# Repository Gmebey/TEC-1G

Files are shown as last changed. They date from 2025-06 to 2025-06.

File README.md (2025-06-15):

# TEC-1G
Collection of Work and Addons for the TEC-1G Z80 Computer

Further information about the TEC-1G
1) Facebook Group:<br>
   -- TEC-1 Z80 Computer Group<br>
   -- https://www.facebook.com/groups/tec1z80/<br>
   
3) Article from HACKADAY.IO:<br>
   -- TEC-1G: 40 year Anniversary Z80 SBC<br>
   -- https://hackaday.io/project/193968-tec-1g-40-year-anniversary-z80-sbc<br>
   
5) Where to purchase:<br>
   -- TEC-1G Z80 Single Board Computer Kit<br>>
   -- https://www.tindie.com/products/tec1/tec-1g-z80-single-board-computer-kit/<br>

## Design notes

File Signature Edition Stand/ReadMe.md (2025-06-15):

File List:<br>
1) Assembly Instructions:    TEC-1G v1.21_Stand.docx<br>
2) 3D Model (Sketchup v8):   TEC-1G_v1.4_Rev1.skp
3) STL Files:                in STLs (folder)

The 7 Segment Display Bazel is from<br>
https://github.com/turbo-gecko/TEC/tree/main/3D%20Printing/7%20Seg%20Bezel

View Top

View Bottom

View Rear

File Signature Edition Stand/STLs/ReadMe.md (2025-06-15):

STL files:
- Rail_Right.stl
- Rail_Center.stl
- Rail_Left.stl
- Leg_Right.stl
- Leg_Center.stl
- Leg_Left.stl
- YP-05_Carrier.stl
- UPS_Frame.stl

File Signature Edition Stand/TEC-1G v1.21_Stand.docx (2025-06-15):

# Overview

This is a revised version of the stand posted by Sean Parkinson for another version of TEC-1G, which didn’t have a compatible hole pattern to the TEC-1G Signature Edition version 1.21 (TEC-1G v1.21SE).

Mark Yelich provided a DXF file for the TEC-1G v1.4SE, which has a compatible hole pattern. The DXF hole pattern file (TEC-1G_Edge-Cuts_v1.4SE.dxf) is available on GitHub.

GitHub - MarkJelic/TEC-1G: The new incarnation of the 40 year old Z80 trainer computer - Now with Fulisik LEDs! (https://github.com/MarkJelic/TEC-1G)

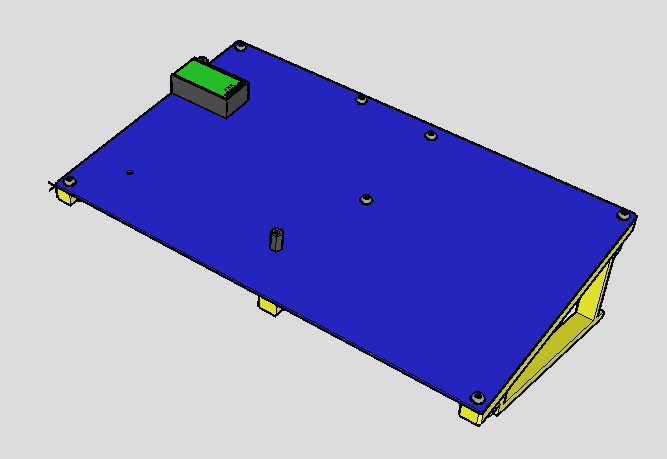
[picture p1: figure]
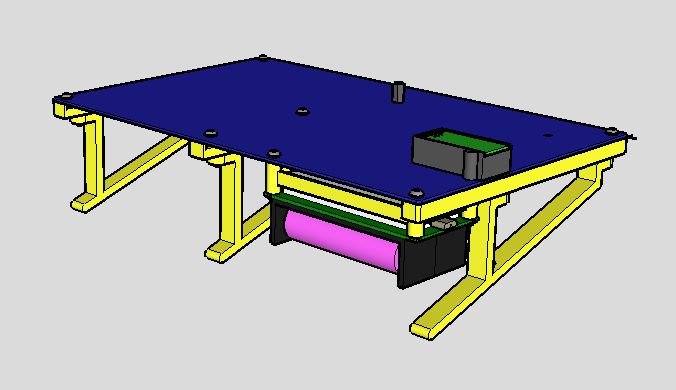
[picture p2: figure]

# Hardware

All mounting holes are intended for M3 button head screws or socket head cap screws. The holes that are provided in the 3D model will need to be drilled out to 2.5mm (#47 bit) and then tapped to M3.

Any metal screw that installed into the TEC-1G has a M3x0.5 Nylon Flat Washer to protect the nearby traces.

List of required hardware:

- 8, M3x0.5mm Nylon Flat Washer
- 9, M3x8mm Button Head Screw
- 6, M3x10mm Button Head Screw
- 1, M3x14mm Button Head Screw
- 1, M3x6mm x 10mm Nylon Hex Standoff (for LCD display)

# 3D Model and STLs

All the 3D modeling was done in an older 3D program called SketchUp (Ver 8) with a Ruby plug-in ( skp_to_dxf.rb) to generate the STLs files.

The Ruby plug in was from:

SketchUp- Exporting/Converting to STL (2013 and Before) | 3D Printer Manufacturers - Airwolf 3D (https://airwolf3d.com/3d-printer-support/encyclopedia/part-design/sketchup-exportingconverting-stl-2013/)

For improved rigidity 3D print with stronger walls.

On the Bambu Lab XC1 printer I used the following:

- 0.4 Nozzle
- Bambu Lab PLA Basic
- Process “0.20mm Strength @BBL XC1”
- Supports: normal(auto)

STL files:

- YP-05_Carrier.STL
- UPS_Frame.STL
- Rail_Right.STL
- Rail_Left.STL
- Rail_Center.STL
- Leg_Right.STL
- Leg_Left.STL
- Leg_Center.STL

# YP-05 USB to TTL UART Module

There is ONE mounting hole that needs to be tapped to M3.

Parts Required:

- 1, YP-05_Carrier.STL
- 1, M3x8mm Button Head Screw
- 1, M3x0.5mm Nylon Flat Washer
- 1, 6-Pos Header Pins (See below)
- 1, 6-Pos Header Socket (See below)

The USB to TTL UART Module carrier is designed to use a combination of header pins and header sockets.

- Pins are Sullins / PRPC036SAAN-RC (gold) or PREC036SAAN-RC (tin)
- Socket is Sullins / PPPC361LFBN-RC (gold) or PPTC361LFBN-RC (tin)

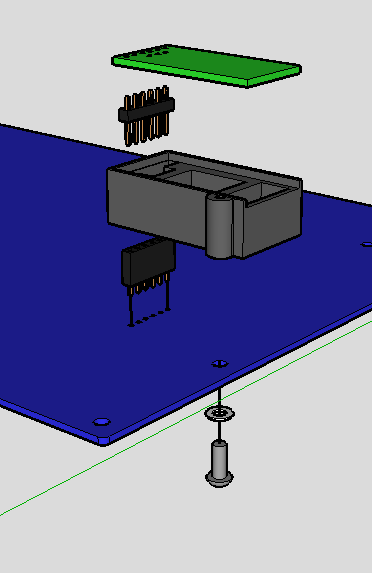
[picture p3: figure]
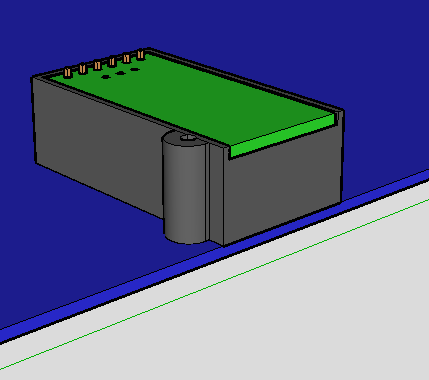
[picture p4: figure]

# Rails

The location of the rails is in reference to viewing the board from the topside with the keypad on the right.

Parts Required:

- 1, Rail_Left.STL
- 1, Rail_ Center.STL
- 1, Rail_ Right.STL
- 6, M3x0.5mm Nylon Flat Washer
- 6, M3x8mm Button Head Screw
- 1, M3x6mm x 10mm Nylon Hex Standoff (for LCD display)

There are three rails, and each rail has at least one hole that needs to be tapped to M3.

- Left
  - It is located under the USB to TTL UART Module
  - It has FOUR holes requiring tapping to M3.
- Center
  - It has FIVE holes requiring tapping to M3.
- Right
  - It is located on the keypad side of the board.
  - It has FIVE holes requiring tapping to M3.

Mount the rails to the board as shown in the diagram below.

There are SIX M3x8mm Button Head Screws that mount the rails to the board, and each screw has a M3x0.5mm Nylon Flat Washer.

The center rail has ONE M3x6mm x 10mm Nylon Hex Standoff that is used for mounting the LCD display.

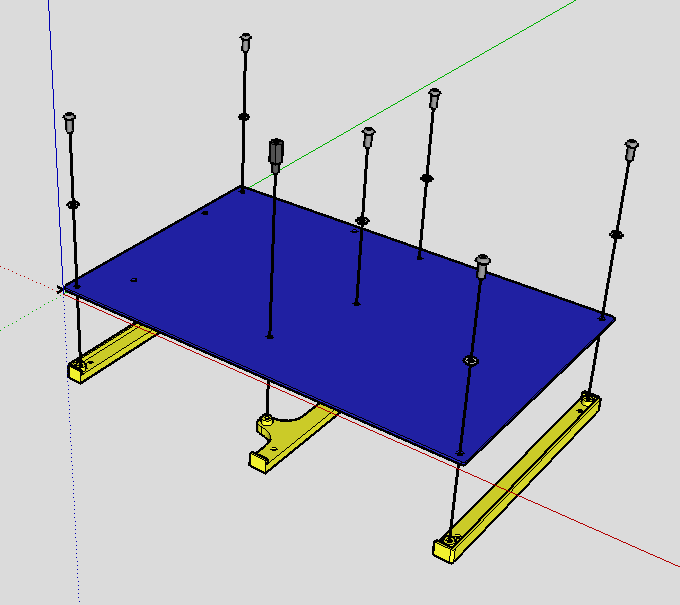
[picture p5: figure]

# UPS Power Source

The UPS mounts on the underside of the board at the upper left (under the 5V regulator).

There is ONE mounting hole that needs to be tapped to M3 in the UPS_Frame and must be taped from BOTH ends.

Parts Required:

- 1, UPS_Frame.STL
- 1, M3x0.5mm Nylon Flat Washer
- 2, M3x8mm Button Head Screw
- 1, M3x14mm Button Head Screw

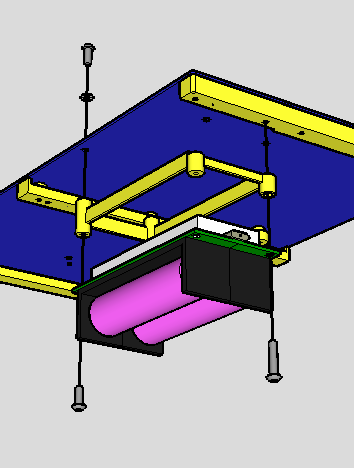
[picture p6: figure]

The UPS batter holder is close to one of the mounting holes. The simplest solution is to use a hobby knife or utility knife to shave away some of the battery holder near the mounting hole.

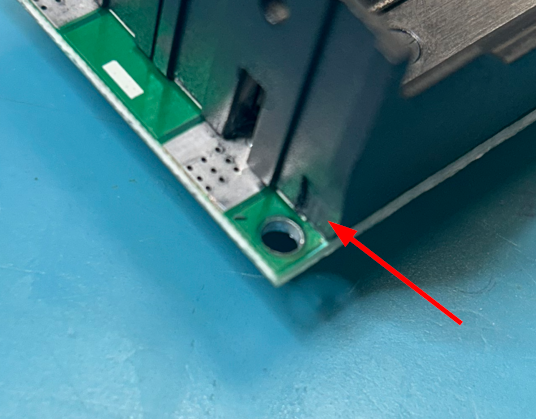
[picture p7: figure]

Place a M3x8mm Button Head Screw into that hole and then attach it to the frame, but do not fully tighten the screw at this point.

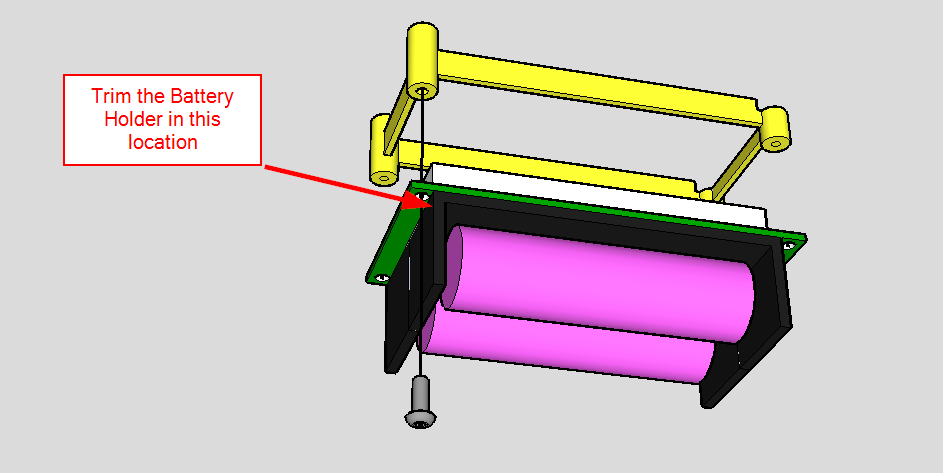
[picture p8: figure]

The UPS is now loosely mounted to the Frame with just one screw.

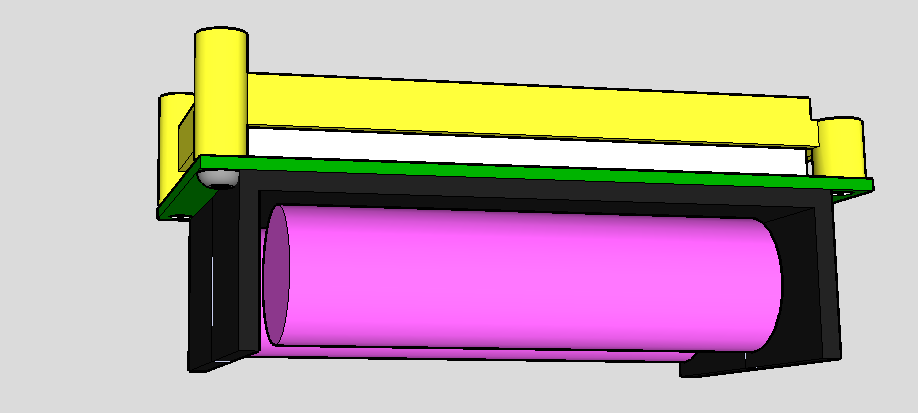
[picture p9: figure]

Set the UPS and Frame on the board and align the hole in the Left Rail.

Install a M3x14mm Button Head Screw and do not fully tighten.

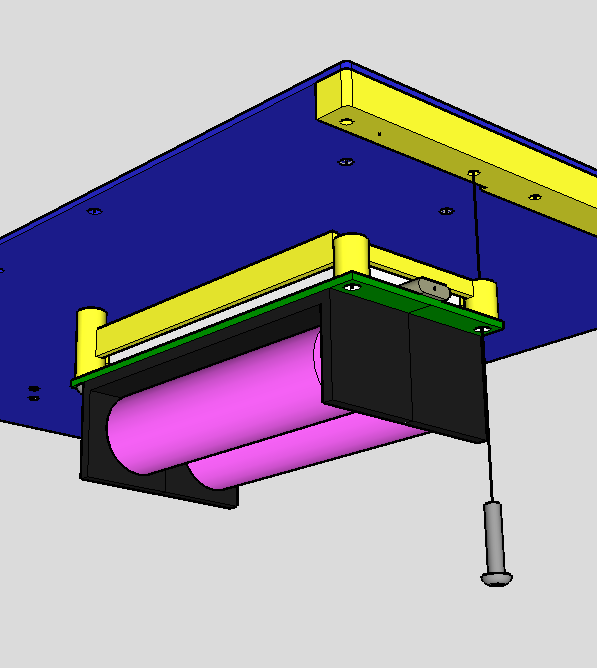
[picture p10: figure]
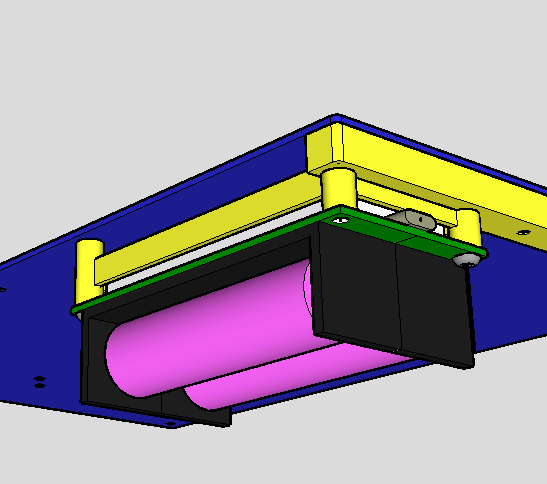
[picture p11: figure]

Install the M3x8mm Button Head Screw and M3x0.5 Nylon Flat Washer on the board side.

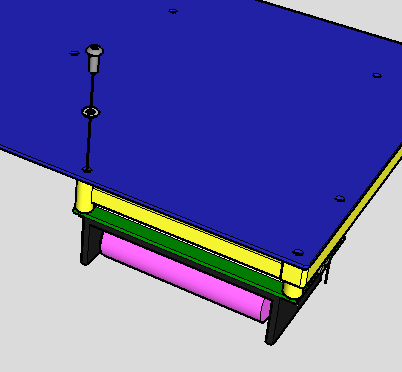
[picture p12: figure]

Now tighten the two prior screws that were installed loosely in the above steps.

This completes the installation of the UPS.

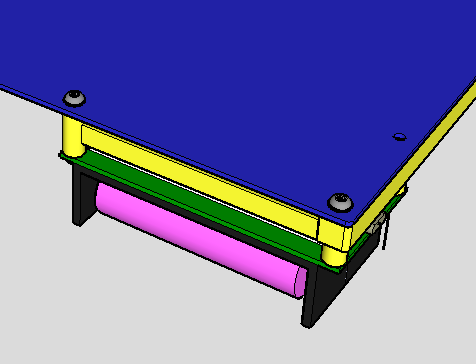
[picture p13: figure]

# Legs

The three legs mount to the rails.

Parts Required:

- 1, Leg_Right.STL
- 1, Leg_Center.STL
- 1, Leg_Left.STL
- 6, M3x10mm Button Head Screw

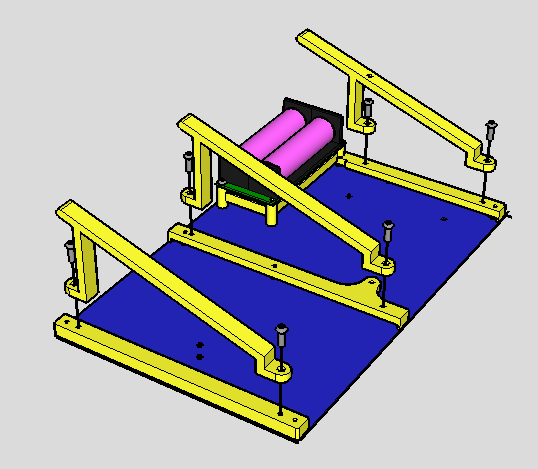
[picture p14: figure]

TEC-1G Stand

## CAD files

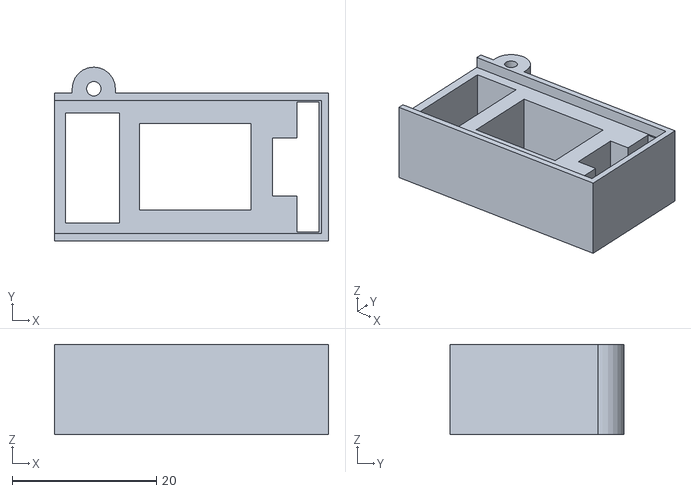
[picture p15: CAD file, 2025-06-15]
Signature Edition Stand/STLs/YP-05_Carrier.stl
38.0 x 24.1 x 12.5

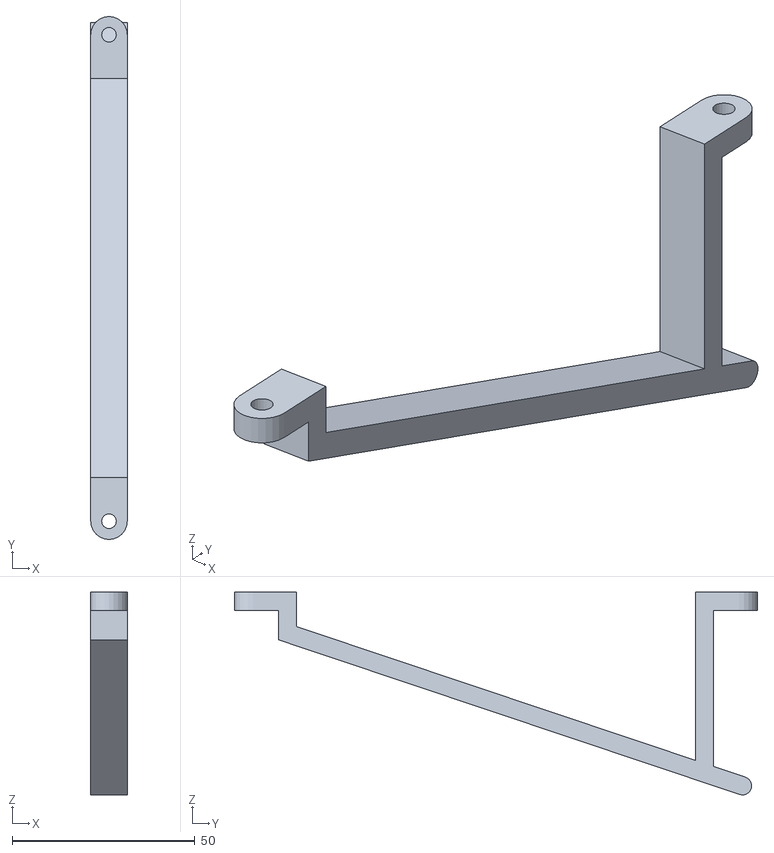
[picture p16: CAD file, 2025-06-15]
Signature Edition Stand/STLs/Leg_Right.stl
10.0 x 143.0 x 55.5

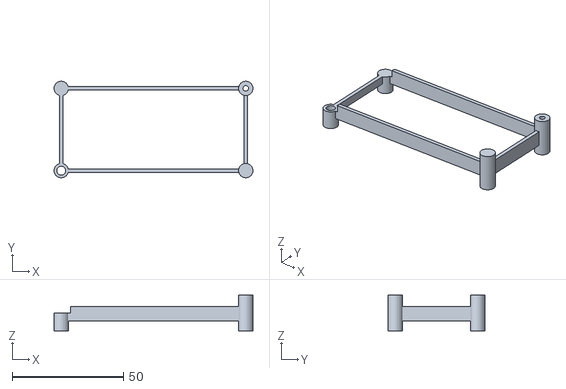
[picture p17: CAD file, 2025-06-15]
Signature Edition Stand/STLs/UPS_Frame.stl
89.5 x 43.5 x 16.0

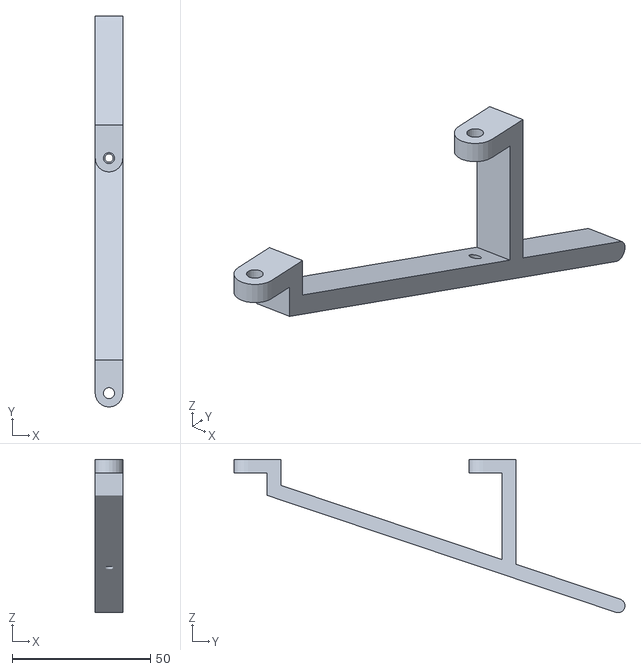
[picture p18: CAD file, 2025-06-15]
Signature Edition Stand/STLs/Leg_Left.stl
10.0 x 141.4 x 55.5

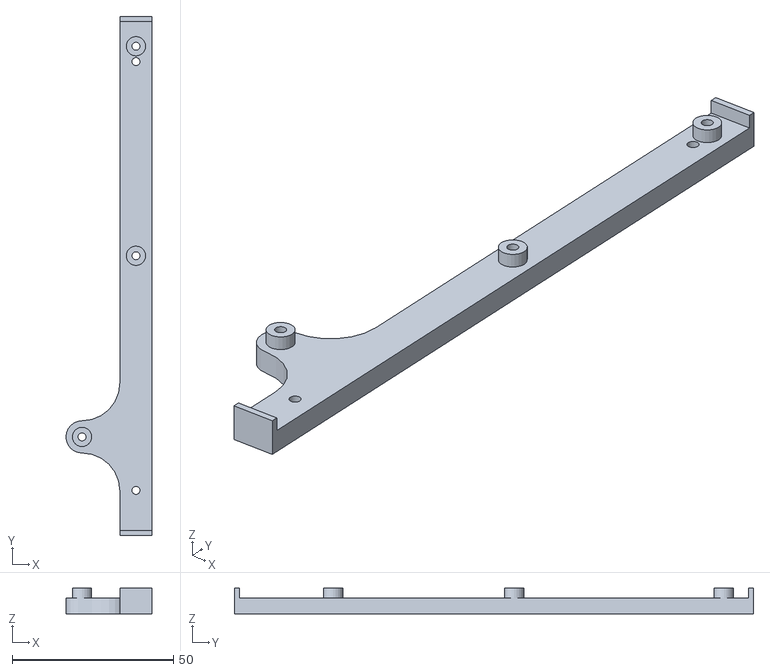
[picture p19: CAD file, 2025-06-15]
Signature Edition Stand/STLs/Rail_Center.stl
26.7 x 161.0 x 8.00

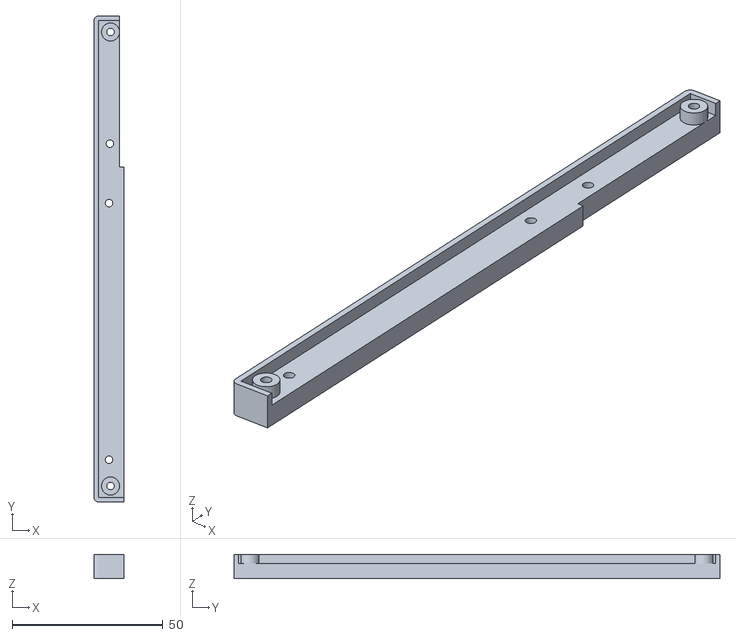
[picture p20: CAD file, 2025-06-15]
Signature Edition Stand/STLs/Rail_Left.stl
9.99 x 161.0 x 8.00

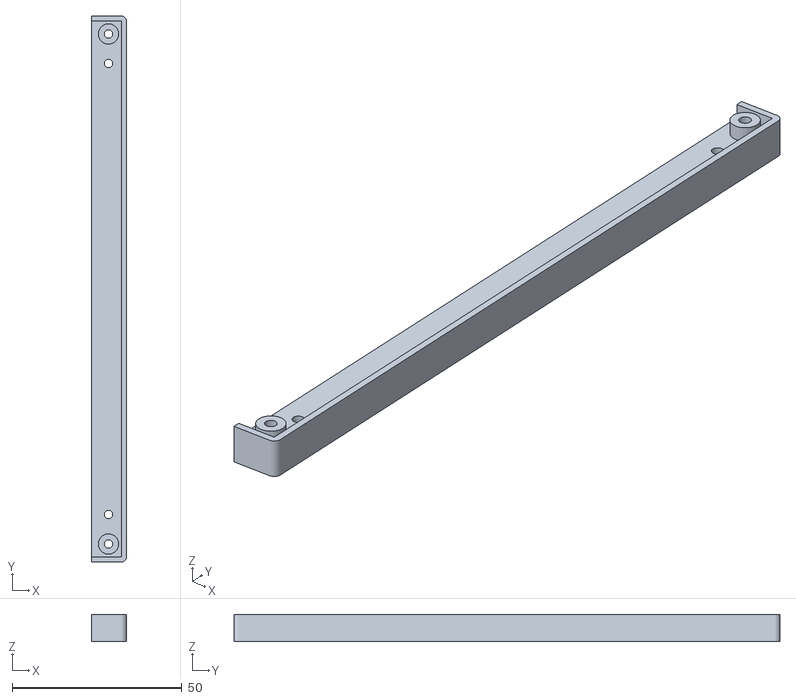
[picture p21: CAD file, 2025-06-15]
Signature Edition Stand/STLs/Rail_Right.stl
10.3 x 161.0 x 8.00

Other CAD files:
Signature Edition Stand/STLs/Leg_Center.stl
Signature Edition Stand/TEC-1G_v1.4_Rev1.skp

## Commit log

2025-06-15 Delete Signature Edition Stand/Leg_Center.stl
    Moved to the STLs folder
    [Leg_Center.stl]
2025-06-15 Delete Signature Edition Stand/Leg_Left.stl
    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
    [Leg_Left.stl]
2025-06-15 Delete Signature Edition Stand/Leg_Right.stl
    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
    [Leg_Right.stl]
2025-06-15 Delete Signature Edition Stand/Rail_Center.stl
    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
    [Rail_Center.stl]
2025-06-15 Delete Signature Edition Stand/UPS_Frame.stl
    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
    [UPS_Frame.stl]
2025-06-15 Delete Signature Edition Stand/YP-05_Carrier.stl
    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
    [YP-05_Carrier.stl]
2025-06-15 Delete Signature Edition Stand/Rail_Left.stl
    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
    [Rail_Left.stl]
2025-06-15 Delete Signature Edition Stand/Rail_Right.stl
    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
    [Rail_Right.stl]
